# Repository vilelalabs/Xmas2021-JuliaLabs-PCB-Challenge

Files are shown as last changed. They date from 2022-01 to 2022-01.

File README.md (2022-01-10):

# Xmas2021-JuliaLabs-PCB-Challenge

## Descrição Geral
Esta placa foi desenvolvida para o concurso "Julialabs PCB Challenge" de 2021 com um tema natalino.
A idéia geral foi fazer um enfeite de para a árvore de natal (a estrela que normalmente é colocada no topo da árvore) que funcione de maneira automática (ao inserir a bateria) fazendo sequências "pisca-pisca" nas pontas principais da mesma (inclusive há buracos na parte interior da placa para se passar uma fita ou linha para afixar a placa na árvore de natal!)
### Funcionamento
Para funcionar ela só precisará de uma bateria 3V tipo CR1220 (facilmente encontrada - a famosa "bateria de relógio") para iniciar automaticamente a apresentação de uma sequências de acendimento de LEDs predefinidos (por software) que destacam os oito cantos principais da estrela.
As sequências (não necessarimanete nesta ordem) são:
-  Alternando os 4 cantos internos (LEDs azuis) e os 4 cantos externos (LEDs brancos)
- Fazendo uma volta completa  piscando no sentido horário e anti-horário
- Piscando todos os Leds acesos e apagados entre estas sequências.

### Hardware
O Hardware foi desenvolvido usando o software [Eagle](https://github.com/vilelalabs/Xmas2021-JuliaLabs-PCB-Challenge/tree/master/HARDWARE/eagle), incluindo aqui:
- O esquemático
- A placa de circuito impresso
- O arquivo gerber para fabricação. 

Já a simulação do funcionamento do circuito foi realizada utilizando o software [Proteus](https://github.com/vilelalabs/Xmas2021-JuliaLabs-PCB-Challenge/tree/master/HARDWARE/proteus).

**_Todos os arquivos referentes ao desenvolvimento do Hardware se encontram na pasta [HARDWARE](https://github.com/vilelalabs/Xmas2021-JuliaLabs-PCB-Challenge/tree/master/HARDWARE)_**

### Software / Firmware
- O software foi desenvolvido em C++ usando a extensão PlatformIO para a IDE VSCode. Nele temos macros (#define) para cada led individualmente e para grupos dos leds (por cor, ou considerandos todos os leds simultaneamente). O código principal pode ser encontrado na pasta [SRC](https://github.com/vilelalabs/Xmas2021-JuliaLabs-PCB-Challenge/tree/master/SOFTWARE/src).
- O código no arquivo **_main.cpp_** também pode ser utilizado normalmente na Arduino IDE, desde que realizadas as devidas configurações para a correta programação do Attiny85 na mesma.

**_Todos arquivos referentes ao desenvolvimento do software no PlatformIO estão na pasta [SOFTWARE](https://github.com/vilelalabs/Xmas2021-JuliaLabs-PCB-Challenge/tree/master/SOFTWARE)_**

### Observações
- Foram usados encapsulamentos SOIC e componentes SMD de solda manual fácil para uma experiência fácil também na montagem.
- Os LEDs devem ser colocados lateralmente (virados para as mesmas direções) ou, se possível, com uma orientação para o lado interno da placa (que poderia ser possível com um "ajuste" na hora da soldagem) aproveitando melhor as partes translúcidas da placa.
- Todo o processo foi transmitido em stream na [Twitch](https://twitch.tv/vilelalabs) e parte desse desenvolvimento será destacado no [Youtube](https://youtube.com/vilelalabs) futuramente.
- Toda parte "verde" da placa deveria ser "azul" **a ser escolhido no momento da fabricação**. Infelizmente nao consegui fazer este setup no Eagle ou nas visualizações do projeto.

### Imagens
|Placa|Esquemático|
|:---:|:---:|
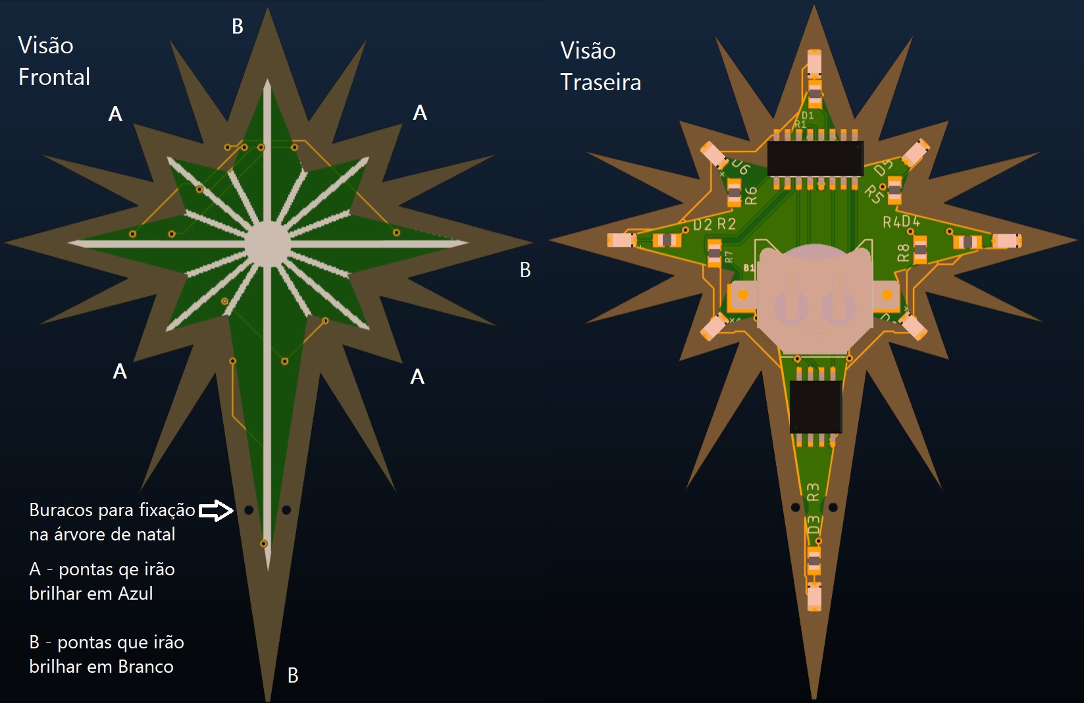
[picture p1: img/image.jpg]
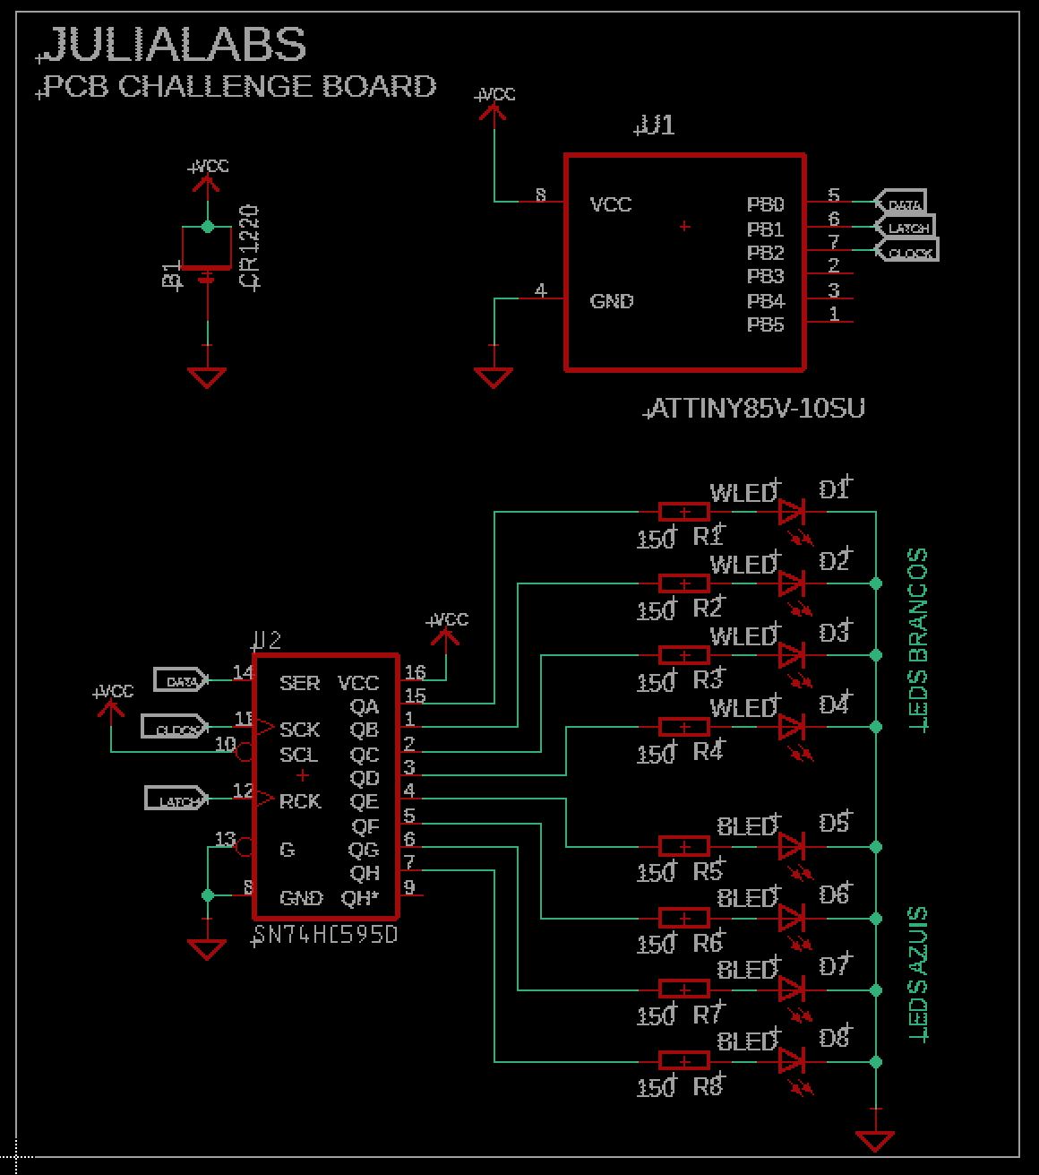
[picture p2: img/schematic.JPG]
|   |  |
|Visualização 3D|Simulação|
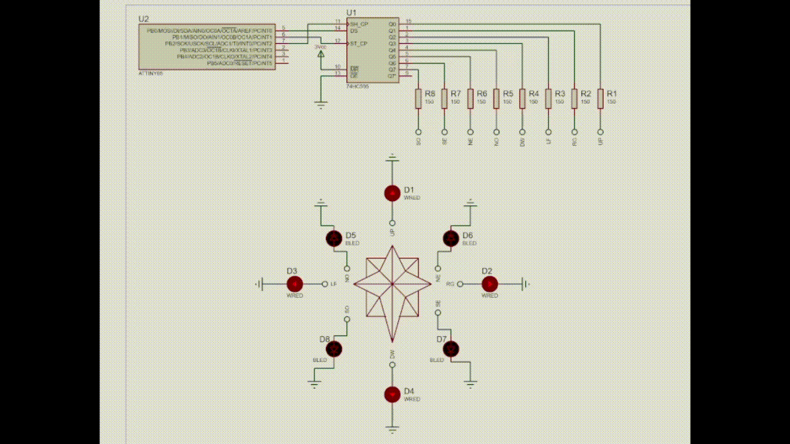
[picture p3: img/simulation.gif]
|   |  |

### Lista de Componentes
|Componente|Quantidade|Observação| Datasheet|
|:---:|:---:|:---:|:---:|
| [ATTINY85V-10SNR](https://br.mouser.com/ProductDetail/556-ATTINY25V-10SNR)  | 1  | Microcontrolador  | [Datasheet](https://br.mouser.com/datasheet/2/268/Atmel-2586-AVR-8-bit-Microcontroller-ATtiny25-ATti-1315542.pdf)|
| [SN74HC595D](https://br.mouser.com/ProductDetail/595-SN74HC595DRE4)  | 1  | Registrador de deslocamento de 8 bits  | [Datasheet](https://www.ti.com/lit/ds/symlink/sn74hc595.pdf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)|
| [Clip de Bateria CR1220](https://br.mouser.com/ProductDetail/534-3000TR)  | 1  | Modelo Keystone 3000TR | [Datasheet](https://br.mouser.com/datasheet/2/215/3000TR-742873.pdf)|
| [Resistor 150Ω](https://br.mouser.com/ProductDetail/71-TNPW0805150RFEEA)  | 8  | Observacao  | [Datasheet](https://br.mouser.com/datasheet/2/427/tnpw_e3-1761965.pdf)|
| [LED Branco](https://br.mouser.com/ProductDetail/720-LWA67CS2U25K8LZ)  | 4  | montagem lateral / SMD  |[Datasheet](https://dammedia.osram.info/media/resource/hires/osram-dam-6455804/LW%20A67C%20binning%20FK0PN0_EN.pdf)|
| [LED Azul](https://br.mouser.com/ProductDetail/859-LTST-S220TBKT)  | 4  | montagem lateral / SMD  |[Datasheet](https://br.mouser.com/datasheet/2/239/Lite-On-LTST-S220TBKT-1175488.pdf)|

### Links
- [Carrinho de compras na Mouser](https://br.mouser.com/ProjectManager/ProjectDetail.aspx?AccessID=1f4f7a85bd)
- [Projeto na PCBWay](https://www.pcbway.com/project/shareproject/Blinking_Christmas_Star_e158be5a.html)

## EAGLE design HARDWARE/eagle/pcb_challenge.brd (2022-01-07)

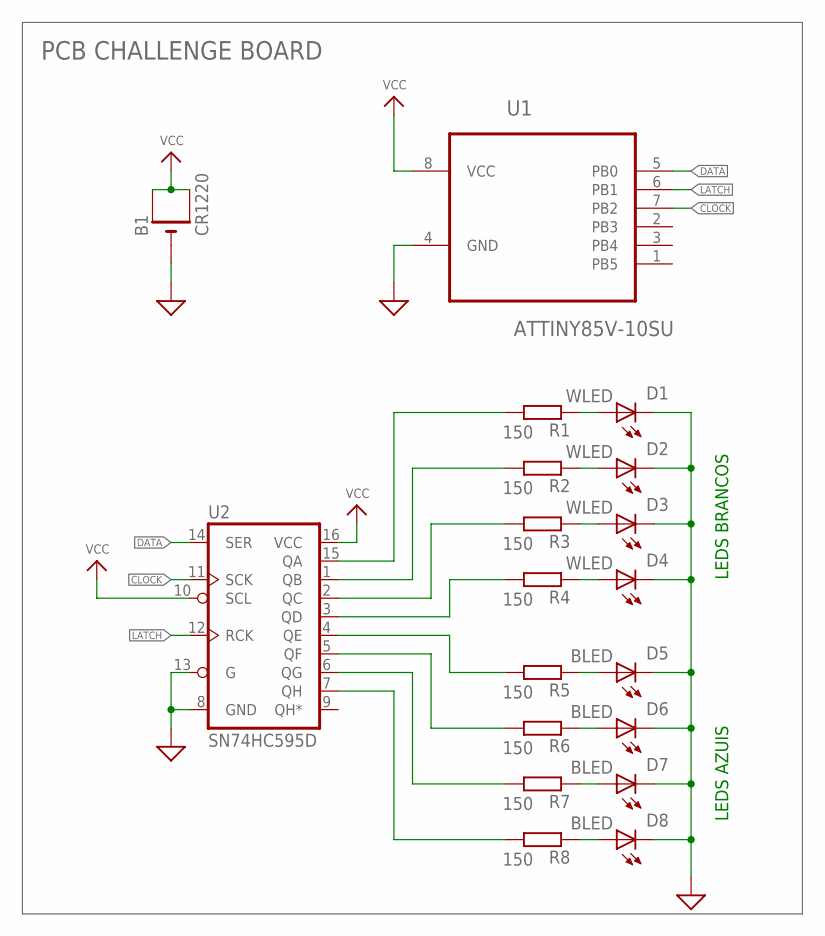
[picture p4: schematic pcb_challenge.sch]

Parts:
B1: CR1220; CR1220-SMD
D1, D2, D3, D4: WLED; CHIP-LED0805
D5, D6, D7, D8: BLED; CHIP-LED0805
R1, R2, R3, R4, R5, R6, R7, R8: 150; R0805
U1: ATTINY85V-10SU; SOIC127P798X216-8N
U2: SN74HC595D; SO16

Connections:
CLOCK: U1.7 (PB2), U2.11 (SCK)
DATA: U1.5 (PB0), U2.14 (SER)
GND: B1.-, D1.C, D2.C, D3.C, D4.C, D5.C, D6.C, D7.C, D8.C, U1.4 (GND), U2.8 (GND), U2.13 (G)
LATCH: U1.6 (PB1), U2.12 (RCK)
unnamed: D5.A, R5.1
unnamed: D4.A, R4.1
unnamed: D3.A, R3.1
unnamed: D2.A, R2.1
unnamed: D1.A, R1.1
unnamed: D8.A, R8.1
unnamed: D7.A, R7.1
unnamed: D6.A, R6.1
unnamed: R1.2, U2.15 (QA)
unnamed: R2.2, U2.1 (QB)
unnamed: R3.2, U2.2 (QC)
unnamed: R4.2, U2.3 (QD)
unnamed: R5.2, U2.4 (QE)
unnamed: R8.2, U2.7 (QH)
unnamed: R7.2, U2.6 (QG)
unnamed: R6.2, U2.5 (QF)
VCC: B1.+$1 (+), B1.+$2 (+1), U1.8 (VCC), U2.10 (SCL), U2.16 (VCC)

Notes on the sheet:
LEDS BRANCOS
LEDS AZUIS
PCB CHALLENGE BOARD

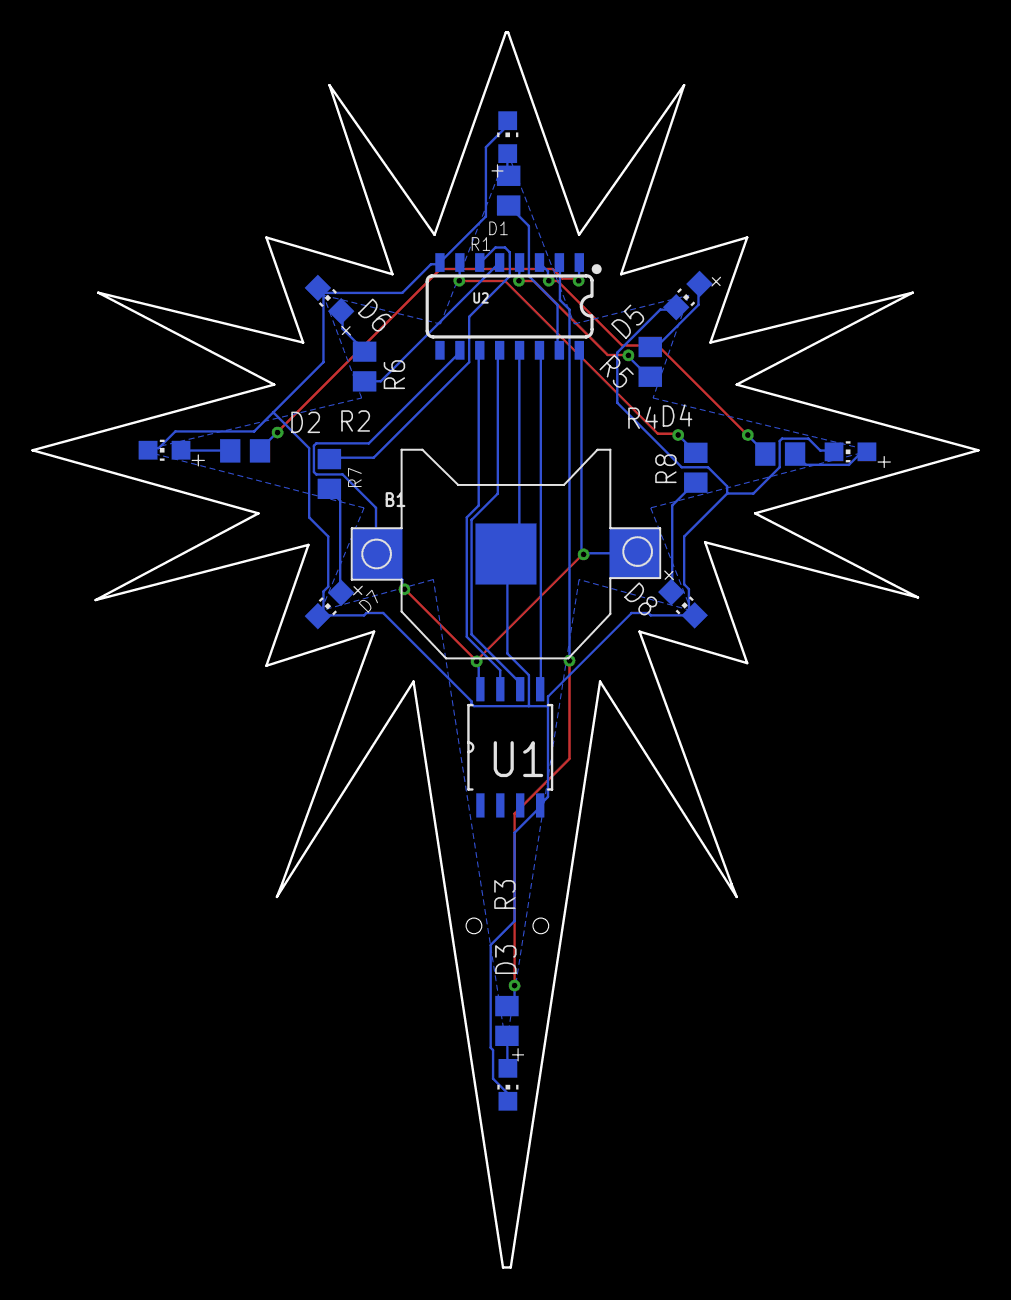
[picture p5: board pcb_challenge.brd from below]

Board: 2 copper layers, 60.4 x 78.8 mm, 19 parts (19 on the bottom side), 21 nets.

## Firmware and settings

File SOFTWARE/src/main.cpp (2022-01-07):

#include <Arduino.h>

#define L0 0b00000000  // Todos LEDS apagados
#define LA 0b11111111  // Todos os LEDs acesos

#define D1 0b00000001  // Leds individuais
#define D2 0b00000010
#define D3 0b00000100
#define D4 0b00001000
#define D5 0b00010000
#define D6 0b00100000
#define D7 0b01000000
#define D8 0b10000000

#define BA 0b11110000  // Leds Azuis acesos
#define WA 0b00001111  // Leds Brancos acesos

// Declare the shift register pins
int dataPin = 0;   // Connected to DS (pin 14) on the 74HC595.
int latchPin = 1;  // Connected to STCP (pin 12) on the 74HC595.
int clockPin = 2;  // Connected to SHCP (pin 11) on the 74HC595.

// prototipo de função
void seq(uint8_t sequencia);
void seqSimples(uint8_t sequencia, int vezes);

void setup() {
  // Set the three shift register pins to output.
  pinMode(clockPin, OUTPUT);
  pinMode(latchPin, OUTPUT);
  pinMode(dataPin, OUTPUT);

  // Start with the clockPin set to a LOW state
  digitalWrite(clockPin, LOW);
}

void loop() {
  // pisca alternando cores
  for (int i = 0; i < 5; i++) {
    seq(BA);
    seq(WA);
  }
  // gira sentido horario
  for (int i = 0; i < 2; i++) {
    seq(D1);
    seq(D6);
    seq(D2);
    seq(D7);
    seq(D4);
    seq(D8);
    seq(D3);
    seq(D5);
  }
  // pisca todos alternando acesso/apagado
  for (int i = 0; i < 5; i++) {
    seq(L0);
    seq(LA);
  }

  // gira sentido anti-horario
  for (int i = 0; i < 2; i++) {
    seq(D1);
    seq(D5);
    seq(D3);
    seq(D8);
    seq(D4);
    seq(D7);
    seq(D2);
    seq(D6);
  }
  seqSimples(L0, 3);
  seqSimples(LA, 3);
  seqSimples(L0, 5);
}
//------------------------------------------------------------------------------
void seq(uint8_t sequencia) {
  digitalWrite(latchPin, LOW);
  shiftOut(dataPin, clockPin, MSBFIRST, sequencia);
  digitalWrite(latchPin, HIGH);
  delay(200);
}
//------------------------------------------------------------------------------
void seqSimples(uint8_t sequencia, int vezes) {
  for (int i = 0; i < vezes; i++) {
    digitalWrite(latchPin, LOW);
    shiftOut(dataPin, clockPin, MSBFIRST, sequencia);
    digitalWrite(latchPin, HIGH);
    delay(200);
  }
}

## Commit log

2022-01-07 Upload eagle files
    [pcb_challenge.brd, pcb_challenge.sch]
2022-01-07 Update README.md
    Tradução para português, adição de campos e formatação.
2022-01-07 Adicionado imagens e BOM
2022-01-07 added gerber file
2022-01-07 new folders
    [pcb_challenge.brd, pcb_challenge.sch]

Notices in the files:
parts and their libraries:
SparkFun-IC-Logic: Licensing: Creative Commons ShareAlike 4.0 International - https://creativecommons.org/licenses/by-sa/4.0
